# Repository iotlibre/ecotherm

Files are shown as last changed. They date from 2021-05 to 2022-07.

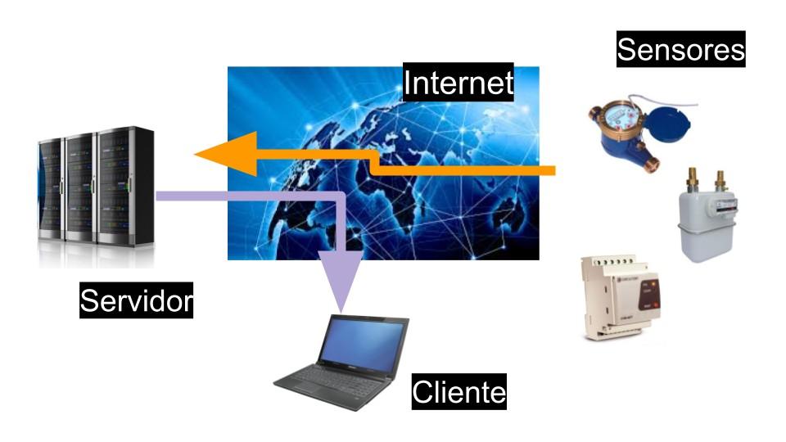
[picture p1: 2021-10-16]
images/iot_general.jpg

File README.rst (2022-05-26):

ecoTherm
==========
ecoTherm is designed to measure the thermal energy of an installation that has one or more water circuits at different temperatures. This device can measure:

* Temperature using 1-wire sensors
* Flow through pulses provided by water meters
* Analog values for both voltage and current.

.. image :: ./images/ecotherm_device.png

For temperature measurement and analog values, samples are taken in one-second intervals. The value provided, each time the information is transmitted, is the average of all the samples taken.

The pulses are measured by interruptions and the value provided, in each reporting period, is the number of interruptions accumulated since the last time the equipment was restarted.

ecoThermal can be installed on a DIN rail at a distance that allows communication with the sensors implemented in the installation. In a building we can have as many devices as are necessary and the server will integrate them in the same installation without the need for additional configurations or firmware changes. Communication is done through Wi-Fi so data cabling to the equipment is not necessary. Only ecoTherm needs to be within the coverage of the building's Wi-Fi network.

To use ecoTherm, computer knowledge is not necessary, although all developments and hardware are made under free licenses, which allows the modification and improvement of functionalities.

Main features
-------------
* 15 configurable inputs
* Supports up to 28 temperature probes spread over 7 buses
* It is possible to integrate up to 15 flow measurements
* Can measure up to 8 analog values
* Accuracy in temperature measurements: ± 0.5 ° C
* The precision of analog measurements depends on the probes used.
* The precision of the flow averages corresponds to the meters implemented
* Internet communication is done by local WIFI
* Configurable via Web
* Standard: IEEE 802.11 b / g / n
* 220 volt AC power supply. Range: 85 ~ 264VAC
* Din rail mounting
* The PCB integrates an Arduino nano with the ESP8266 12E
* Implements the MQTT protocol
* Compatible with `emonCMS <https://emoncms.org>`_

Hardware
--------
The hardware design is based on two PCBs that are interconnected by a ribbon cable. These two cards are machined in a din rail housing. This entire system is powered by 5 volt power supply. 

.. image :: ./images/ecotherm_board.png

Start up
--------
The ecoThermal set-up consists of three parts:

* Hardware configuration
* The Arduino firmware
* Configuration on installation

Hardware configuration
~~~~~~~~~~~~~~~~~~~~~~
The default hardware is prepared for 8 analog inputs, 3 flow rates and 16 temperature probes divided into 4 buses. However, this configuration can be modified by changing the surface components of the PCB until the combination of measures that best suits the project.

Arduino firmware
~~~~~~~~~~~~~~~~
The firmware that is loaded, by default, in the Arduino nano works correctly with the hardware configuration, by default. In the case of changing the hardware, it is also necessary to change the firmware of the Arduino integrated in the PCB and that can be found in the source code.

An ESP 8266 has been used for the internet connection. The firmware used for its operation has been developed by Open Energy Monintor and can be found at https://github.com/openenergymonitor/EmonESP. 

Configuration at installation
~~~~~~~~~~~~~~~~~~~~~~~~~~~~~
At this point, the parameters of the destination server and the local Wi-Fi to which the device will be connected are defined. To this end, the first time the ESP 8266 12E is put into service it will create its own access point, its own WIFI network. By connecting to any address, through this access point, the ESP configuration page will appear. Bear in mind that once ESP is configured and connected to a WIFI network, the router will assign you a single IP address that will be necessary to access to change the configuration.
The ESP configuration details can be found in the `repository <https: //github.com/openenergymonitor/EmonESP>`_

Source code
~~~~~~~~~~~
Copyright 2021 Endef Engineering SL.

Firmware code and hardware documentation can be found in this `repository <https://github.com/iotlibre/ecoTherm>`_ 

Both the hardware and the software of this repository have been developed by the company `Endef Engineering <https://endef.com/en/>`_ 

Licence
-------
* The hardware designs are licensed under a Creative Commons Attribution-ShareAlike 3.0 Unported License.
* The firmware is released under the GNU GPL V3 license The documentation is subject to GNU Free Documentation License
* The hardware designs follow the terms of the OSHW (Open-source hardware) Statement of Principles 1.0.

Disclaimer
----------

All the code found in this repository is under the license: "GNU V3 General Public License" so the conditions of its use are those included in this license

OUR PRODUCTS AND ASSEMBLY KITS MAY BE USED BY EXPERIENCED, SKILLED USERS, AT THEIR OWN RISK. TO THE FULLEST EXTENT PERMISSIBLE BY THE APPLICABLE LAW, WE HEREBY DISCLAIM ANY AND ALL RESPONSIBILITY, RISK, LIABILITY AND DAMAGES ARISING OUT OF DEATH OR PERSONAL INJURY RESULTING FROM ASSEMBLY OR OPERATION OF OUR PRODUCTS.

Your safety is your own responsibility, including proper use of equipment and safety gear, and determining whether you have adequate skill and experience. OEndef Engineering disclaims all responsibility for any resulting damage, injury, or expense. It is your responsibility to make sure that your activities comply with applicable laws, including copyright. There may be important updates or corrections. All use of the instructions, kits, projects and suggestions given by Endef Engineering are to be used at your own risk. The technology (hardware , firmware and software) are constantly changing, documentation (including build guide and instructions) may not be complete or correct.

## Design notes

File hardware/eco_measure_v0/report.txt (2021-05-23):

Información: Comprobando la huella del símbolo de la red "R15:/5FFCF40F:eco_power_v2:R_1206_HandSoldering".

Información: Comprobando la huella del símbolo de la red "C9:/5FF955E2:eco_power_v2:C_1206_HandSoldering".

Información: Comprobando la huella del símbolo de la red "R1:/5FFB1A2C:eco_power_v2:R_1206_HandSoldering".

Información: Comprobando la huella del símbolo de la red "C10:/5FFCF401:eco_power_v2:C_1206_HandSoldering".

Información: Comprobando la huella del símbolo de la red "R12:/5FFD79E8:eco_power_v2:R_1206_HandSoldering".

Información: Comprobando la huella del símbolo de la red "C11:/5FFD4082:eco_power_v2:C_1206_HandSoldering".

Información: Comprobando la huella del símbolo de la red "C12:/5FFD40B3:eco_power_v2:C_1206_HandSoldering".

Información: Comprobando la huella del símbolo de la red "R13:/5FFD7A19:eco_power_v2:R_1206_HandSoldering".

Información: Comprobando la huella del símbolo de la red "C13:/5FFD79D3:eco_power_v2:C_1206_HandSoldering".

Información: Comprobando la huella del símbolo de la red "U1:/5D4E51E2:eco_power_v2:arduino_nano".

Información: Comprobando la huella del símbolo de la red "R14:/5FF955F0:eco_power_v2:R_1206_HandSoldering".

Información: Comprobando la huella del símbolo de la red "C14:/5FFD7A04:eco_power_v2:C_1206_HandSoldering".

Información: Comprobando la huella del símbolo de la red "J5:/601390B1:TerminalBlock:TerminalBlock_bornier-6_P5.08mm".

Información: Comprobando la huella del símbolo de la red "R23:/5FFEF008:eco_power_v2:R_1206_HandSoldering".

Información: Comprobando la huella del símbolo de la red "C15:/5FFEEFC9:eco_power_v2:C_1206_HandSoldering".

Información: Comprobando la huella del símbolo de la red "P1:/5FF18B83:eco_power_v2:TerminalBlock_bornier-2_P5.08mm".

Información: Comprobando la huella del símbolo de la red "C16:/5FFEEFFA:eco_power_v2:C_1206_HandSoldering".

Información: Comprobando la huella del símbolo de la red "R22:/5FFEEFD7:eco_power_v2:R_1206_HandSoldering".

Información: Comprobando la huella del símbolo de la red "D1:/5D4E44AF:eco_power_v2:D_2114".

Información: Comprobando la huella del símbolo de la red "J1:/5D4CBA5C:eco_power_v2:Pin_Header_Straight_2x05_Pitch2.54mm_onsar".

Información: Comprobando la huella del símbolo de la red "R21:/5FFEF00F:eco_power_v2:R_1206_HandSoldering".

Información: Comprobando la huella del símbolo de la red "J4:/6011E7C7:TerminalBlock:TerminalBlock_bornier-6_P5.08mm".

Información: Comprobando la huella del símbolo de la red "R16:/5FFD4090:eco_power_v2:R_1206_HandSoldering".

Información: Comprobando la huella del símbolo de la red "R20:/5FFEEFDE:eco_power_v2:R_1206_HandSoldering".

Información: Comprobando la huella del símbolo de la red "J3:/60139D5D:TerminalBlock:TerminalBlock_bornier-3_P5.08mm".

Información: Comprobando la huella del símbolo de la red "R19:/5FFD7A12:eco_power_v2:R_1206_HandSoldering".

Información: Comprobando la huella del símbolo de la red "R17:/5FFD40C1:eco_power_v2:R_1206_HandSoldering".

Información: Comprobando la huella del símbolo de la red "J2:/60138EF1:TerminalBlock:TerminalBlock_bornier-6_P5.08mm".

Información: Comprobando la huella del símbolo de la red "R18:/5FFD79E1:eco_power_v2:R_1206_HandSoldering".

Información: Comprobando la huella del símbolo de la red "R2:/5FFFA8B2:eco_power_v2:R_1206_HandSoldering".

Información: Comprobando la huella del símbolo de la red "C3:/5FFFA89D:eco_power_v2:C_1206_HandSoldering".

Información: Comprobando la huella del símbolo de la red "C4:/5FFFF00A:eco_power_v2:C_1206_HandSoldering".

Información: Comprobando la huella del símbolo de la red "C5:/6004F39B:eco_power_v2:C_1206_HandSoldering".

Información: Comprobando la huella del símbolo de la red "R9:/5FFCF416:eco_power_v2:R_1206_HandSoldering".

Información: Comprobando la huella del símbolo de la red "R5:/6004F3D3:eco_power_v2:R_1206_HandSoldering".

Información: Comprobando la huella del símbolo de la red "C6:/6004F3BE:eco_power_v2:C_1206_HandSoldering".

Información: Comprobando la huella del símbolo de la red "R6:/6004F3F6:eco_power_v2:R_1206_HandSoldering".

Información: Comprobando la huella del símbolo de la red "R10:/5FFD4097:eco_power_v2:R_1206_HandSoldering".

Información: Comprobando la huella del símbolo de la red "C2:/5FFB1A03:eco_power_v2:C_1206_HandSoldering".

Información: Comprobando la huella del símbolo de la red "R4:/6004F3B0:eco_power_v2:R_1206_HandSoldering".

Información: Comprobando la huella del símbolo de la red "C7:/6004F3E1:eco_power_v2:C_1206_HandSoldering".

Información: Comprobando la huella del símbolo de la red "R11:/5FFD40C8:eco_power_v2:R_1206_HandSoldering".

Información: Comprobando la huella del símbolo de la red "R8:/5FF955F7:eco_power_v2:R_1206_HandSoldering".

Información: Comprobando la huella del símbolo de la red "C1:/5FF18B84:eco_power_v2:C_2220_HandSoldering".

Información: Comprobando la huella del símbolo de la red "W1:/5FF18B86:eco_power_v2:SolderWirePad_single_0-8mmDrill".

Información: Comprobando la huella del símbolo de la red "R7:/60054BE6:eco_power_v2:R_1206_HandSoldering".

Información: Comprobando la huella del símbolo de la red "R3:/5FFFF01F:eco_power_v2:R_1206_HandSoldering".

Información: Comprobando la huella del símbolo de la red "C8:/60054BD1:eco_power_v2:C_1206_HandSoldering".

Añadiendo del nuevo símbolo "R17:/5FFD40C1" la huella "eco_power_v2:R_1206_HandSoldering".

Cambiando de la huella "R3:/5FFFF01F" el nombre de la red del pad "2" de "" a "VCC".

Cambiando de la huella "R17:/5FFD40C1" el nombre de la red del pad "2" de "" a "/A3".

Añadiendo del nuevo símbolo "R15:/5FFCF40F" la huella "eco_power_v2:R_1206_HandSoldering".

Cambiando de la huella "R15:/5FFCF40F" el nombre de la red del pad "2" de "" a "/A1".

Cambiando de la huella "R8:/5FF955F7" el nombre de la red del pad "2" de "" a "/jA0".

Cambiando de la huella "R15:/5FFCF40F" el nombre de la red del pad "1" de "" a "GND".

Cambiando de la huella "R16:/5FFD4090" el nombre de la red del pad "2" de "" a "/A2".

Cambiando de la huella "R8:/5FF955F7" el nombre de la red del pad "1" de "" a "/A0".

Añadiendo del nuevo símbolo "R16:/5FFD4090" la huella "eco_power_v2:R_1206_HandSoldering".

Cambiando de la huella "R16:/5FFD4090" el nombre de la red del pad "1" de "" a "GND".

Añadiendo del nuevo símbolo "R8:/5FF955F7" la huella "eco_power_v2:R_1206_HandSoldering".

Añadiendo del nuevo símbolo "R10:/5FFD4097" la huella "eco_power_v2:R_1206_HandSoldering".

Añadiendo del nuevo símbolo "R11:/5FFD40C8" la huella "eco_power_v2:R_1206_HandSoldering".

Cambiando de la huella "R11:/5FFD40C8" el nombre de la red del pad "2" de "" a "/jA3".

Cambiando de la huella "R11:/5FFD40C8" el nombre de la red del pad "1" de "" a "/A3".

Cambiando de la huella "R10:/5FFD4097" el nombre de la red del pad "2" de "" a "/jA2".

Añadiendo del nuevo símbolo "R12:/5FFD79E8" la huella "eco_power_v2:R_1206_HandSoldering".

Cambiando de la huella "R10:/5FFD4097" el nombre de la red del pad "1" de "" a "/A2".

Cambiando de la huella "R7:/60054BE6" el nombre de la red del pad "2" de "" a "VCC".

Cambiando de la huella "R12:/5FFD79E8" el nombre de la red del pad "1" de "" a "/A4".

Cambiando de la huella "R12:/5FFD79E8" el nombre de la red del pad "2" de "" a "/jA4".

Cambiando de la huella "R14:/5FF955F0" el nombre de la red del pad "1" de "" a "GND".

Añadiendo del nuevo símbolo "R13:/5FFD7A19" la huella "eco_power_v2:R_1206_HandSoldering".

Cambiando de la huella "R13:/5FFD7A19" el nombre de la red del pad "2" de "" a "/jA5".

Cambiando de la huella "R13:/5FFD7A19" el nombre de la red del pad "1" de "" a "/A5".

Cambiando de la huella "R9:/5FFCF416" el nombre de la red del pad "2" de "" a "/jA1".

Cambiando de la huella "R9:/5FFCF416" el nombre de la red del pad "1" de "" a "/A1".

Añadiendo del nuevo símbolo "R14:/5FF955F0" la huella "eco_power_v2:R_1206_HandSoldering".

Añadiendo del nuevo símbolo "R9:/5FFCF416" la huella "eco_power_v2:R_1206_HandSoldering".

Cambiando de la huella "R14:/5FF955F0" el nombre de la red del pad "2" de "" a "/A0".

Cambiando de la huella "U1:/5D4E51E2" el nombre de la red del pad "1" de "" a "/ard_tx".

Cambiando de la huella "U1:/5D4E51E2" el nombre de la red del pad "16" de "" a "/D13".

Cambiando de la huella "U1:/5D4E51E2" el nombre de la red del pad "15" de "" a "/D12".

Cambiando de la huella "U1:/5D4E51E2" el nombre de la red del pad "14" de "" a "/D11".

Cambiando de la huella "U1:/5D4E51E2" el nombre de la red del pad "13" de "" a "/D10".

Cambiando de la huella "U1:/5D4E51E2" el nombre de la red del pad "12" de "" a "/D9".

Cambiando de la huella "U1:/5D4E51E2" el nombre de la red del pad "11" de "" a "/D8".

Cambiando de la huella "U1:/5D4E51E2" el nombre de la red del pad "10" de "" a "/D7".

Cambiando de la huella "U1:/5D4E51E2" el nombre de la red del pad "9" de "" a "/D6".

Cambiando de la huella "U1:/5D4E51E2" el nombre de la red del pad "8" de "" a "Net-(U1-Pad8)".

Cambiando de la huella "U1:/5D4E51E2" el nombre de la red del pad "7" de "" a "/D4".

Cambiando de la huella "U1:/5D4E51E2" el nombre de la red del pad "6" de "" a "/D3".

Cambiando de la huella "U1:/5D4E51E2" el nombre de la red del pad "5" de "" a "/D2".

Cambiando de la huella "U1:/5D4E51E2" el nombre de la red del pad "20" de "" a "/A1".

Cambiando de la huella "U1:/5D4E51E2" el nombre de la red del pad "17" de "" a "Net-(U1-Pad17)".

Cambiando de la huella "U1:/5D4E51E2" el nombre de la red del pad "18" de "" a "Net-(U1-Pad18)".

Cambiando de la huella "U1:/5D4E51E2" el nombre de la red del pad "19" de "" a "/A0".

Cambiando de la huella "U1:/5D4E51E2" el nombre de la red del pad "27" de "" a "VCC".

Cambiando de la huella "U1:/5D4E51E2" el nombre de la red del pad "28" de "" a "Net-(U1-Pad28)".

Cambiando de la huella "U1:/5D4E51E2" el nombre de la red del pad "29" de "" a "GND".

Cambiando de la huella "U1:/5D4E51E2" el nombre de la red del pad "30" de "" a "Net-(U1-Pad30)".

Cambiando de la huella "U1:/5D4E51E2" el nombre de la red del pad "4" de "" a "GND".

Cambiando de la huella "U1:/5D4E51E2" el nombre de la red del pad "3" de "" a "Net-(U1-Pad3)".

Cambiando de la huella "U1:/5D4E51E2" el nombre de la red del pad "2" de "" a "/ard_rx".

Añadiendo del nuevo símbolo "W1:/5FF18B86" la huella "eco_power_v2:SolderWirePad_single_0-8mmDrill".

Cambiando de la huella "W1:/5FF18B86" el nombre de la red del pad "1" de "" a "VCC".

Añadiendo del nuevo símbolo "R22:/5FFEEFD7" la huella "eco_power_v2:R_1206_HandSoldering".

Añadiendo del nuevo símbolo "R18:/5FFD79E1" la huella "eco_power_v2:R_1206_HandSoldering".

Cambiando de la huella "R18:/5FFD79E1" el nombre de la red del pad "2" de "" a "/A4".

Cambiando de la huella "R18:/5FFD79E1" el nombre de la red del pad "1" de "" a "GND".

Añadiendo del nuevo símbolo "R19:/5FFD7A12" la huella "eco_power_v2:R_1206_HandSoldering".

Cambiando de la huella "R19:/5FFD7A12" el nombre de la red del pad "1" de "" a "GND".

Cambiando de la huella "R19:/5FFD7A12" el nombre de la red del pad "2" de "" a "/A5".

Añadiendo del nuevo símbolo "R20:/5FFEEFDE" la huella "eco_power_v2:R_1206_HandSoldering".

Cambiando de la huella "R20:/5FFEEFDE" el nombre de la red del pad "2" de "" a "/jA6".

Cambiando de la huella "R20:/5FFEEFDE" el nombre de la red del pad "1" de "" a "/A6".

Añadiendo del nuevo símbolo "R21:/5FFEF00F" la huella "eco_power_v2:R_1206_HandSoldering".

Cambiando de la huella "R21:/5FFEF00F" el nombre de la red del pad "2" de "" a "/jA7".

Cambiando de la huella "R21:/5FFEF00F" el nombre de la red del pad "1" de "" a "/A7".

Cambiando de la huella "R17:/5FFD40C1" el nombre de la red del pad "1" de "" a "GND".

Cambiando de la huella "R22:/5FFEEFD7" el nombre de la red del pad "1" de "" a "GND".

Cambiando de la huella "R22:/5FFEEFD7" el nombre de la red del pad "2" de "" a "/A6".

Añadiendo del nuevo símbolo "R23:/5FFEF008" la huella "eco_power_v2:R_1206_HandSoldering".

Cambiando de la huella "R23:/5FFEF008" el nombre de la red del pad "1" de "" a "GND".

Cambiando de la huella "R23:/5FFEF008" el nombre de la red del pad "2" de "" a "/A7".

Añadiendo del nuevo símbolo "U1:/5D4E51E2" la huella "eco_power_v2:arduino_nano".

Cambiando de la huella "U1:/5D4E51E2" el nombre de la red del pad "26" de "" a "/A7".

Cambiando de la huella "U1:/5D4E51E2" el nombre de la red del pad "25" de "" a "/A6".

Cambiando de la huella "U1:/5D4E51E2" el nombre de la red del pad "24" de "" a "/A5".

Cambiando de la huella "U1:/5D4E51E2" el nombre de la red del pad "23" de "" a "/A4".

Cambiando de la huella "U1:/5D4E51E2" el nombre de la red del pad "22" de "" a "/A3".

Cambiando de la huella "U1:/5D4E51E2" el nombre de la red del pad "21" de "" a "/A2".

Añadiendo del nuevo símbolo "C15:/5FFEEFC9" la huella "eco_power_v2:C_1206_HandSoldering".

Añadiendo del nuevo símbolo "C11:/5FFD4082" la huella "eco_power_v2:C_1206_HandSoldering".

Cambiando de la huella "C11:/5FFD4082" el nombre de la red del pad "2" de "" a "GND".

Cambiando de la huella "C11:/5FFD4082" el nombre de la red del pad "1" de "" a "/A2".

Añadiendo del nuevo símbolo "C12:/5FFD40B3" la huella "eco_power_v2:C_1206_HandSoldering".

Cambiando de la huella "C12:/5FFD40B3" el nombre de la red del pad "1" de "" a "/A3".

Cambiando de la huella "C12:/5FFD40B3" el nombre de la red del pad "2" de "" a "GND".

Añadiendo del nuevo símbolo "C13:/5FFD79D3" la huella "eco_power_v2:C_1206_HandSoldering".

Cambiando de la huella "C13:/5FFD79D3" el nombre de la red del pad "2" de "" a "GND".

Cambiando de la huella "C13:/5FFD79D3" el nombre de la red del pad "1" de "" a "/A4".

Añadiendo del nuevo símbolo "C14:/5FFD7A04" la huella "eco_power_v2:C_1206_HandSoldering".

Cambiando de la huella "C14:/5FFD7A04" el nombre de la red del pad "1" de "" a "/A5".

Cambiando de la huella "C14:/5FFD7A04" el nombre de la red del pad "2" de "" a "GND".

Cambiando de la huella "C10:/5FFCF401" el nombre de la red del pad "2" de "" a "GND".

Cambiando de la huella "C15:/5FFEEFC9" el nombre de la red del pad "1" de "" a "/A6".

Cambiando de la huella "C15:/5FFEEFC9" el nombre de la red del pad "2" de "" a "GND".

Añadiendo del nuevo símbolo "C16:/5FFEEFFA" la huella "eco_power_v2:C_1206_HandSoldering".

Cambiando de la huella "C16:/5FFEEFFA" el nombre de la red del pad "2" de "" a "GND".

Cambiando de la huella "C16:/5FFEEFFA" el nombre de la red del pad "1" de "" a "/A7".

Añadiendo del nuevo símbolo "J1:/5D4CBA5C" la huella "eco_power_v2:Pin_Header_Straight_2x05_Pitch2.54mm_onsar".

Cambiando de la huella "J1:/5D4CBA5C" el nombre de la red del pad "10" de "" a "GND".

Cambiando de la huella "J1:/5D4CBA5C" el nombre de la red del pad "9" de "" a "/vcc_5v".

Cambiando de la huella "J1:/5D4CBA5C" el nombre de la red del pad "8" de "" a "/D9".

Cambiando de la huella "J1:/5D4CBA5C" el nombre de la red del pad "7" de "" a "/vcc_5v".

Cambiando de la huella "J1:/5D4CBA5C" el nombre de la red del pad "6" de "" a "/D8".

Cambiando de la huella "C6:/6004F3BE" el nombre de la red del pad "2" de "" a "GND".

Añadiendo del nuevo símbolo "C1:/5FF18B84" la huella "eco_power_v2:C_2220_HandSoldering".

Cambiando de la huella "C1:/5FF18B84" el nombre de la red del pad "2" de "" a "GND".

Cambiando de la huella "C1:/5FF18B84" el nombre de la red del pad "1" de "" a "VCC".

Añadiendo del nuevo símbolo "C2:/5FFB1A03" la huella "eco_power_v2:C_1206_HandSoldering".

Cambiando de la huella "C2:/5FFB1A03" el nombre de la red del pad "2" de "" a "GND".

Cambiando de la huella "C2:/5FFB1A03" el nombre de la red del pad "1" de "" a "/D2".

Añadiendo del nuevo símbolo "C5:/6004F39B" la huella "eco_power_v2:C_1206_HandSoldering".

Cambiando de la huella "C5:/6004F39B" el nombre de la red del pad "2" de "" a "GND".

Cambiando de la huella "C5:/6004F39B" el nombre de la red del pad "1" de "" a "/D10".

Añadiendo del nuevo símbolo "C6:/6004F3BE" la huella "eco_power_v2:C_1206_HandSoldering".

Cambiando de la huella "C6:/6004F3BE" el nombre de la red del pad "1" de "" a "/D11".

Añadiendo del nuevo símbolo "R7:/60054BE6" la huella "eco_power_v2:R_1206_HandSoldering".

Añadiendo del nuevo símbolo "C7:/6004F3E1" la huella "eco_power_v2:C_1206_HandSoldering".

Cambiando de la huella "C7:/6004F3E1" el nombre de la red del pad "2" de "" a "GND".

Cambiando de la huella "C7:/6004F3E1" el nombre de la red del pad "1" de "" a "/D12".

Añadiendo del nuevo símbolo "C8:/60054BD1" la huella "eco_power_v2:C_1206_HandSoldering".

Cambiando de la huella "C8:/60054BD1" el nombre de la red del pad "1" de "" a "/D13".

Cambiando de la huella "C8:/60054BD1" el nombre de la red del pad "2" de "" a "GND".

Añadiendo del nuevo símbolo "C9:/5FF955E2" la huella "eco_power_v2:C_1206_HandSoldering".

Cambiando de la huella "C9:/5FF955E2" el nombre de la red del pad "2" de "" a "GND".

Cambiando de la huella "C9:/5FF955E2" el nombre de la red del pad "1" de "" a "/A0".

Añadiendo del nuevo símbolo "C10:/5FFCF401" la huella "eco_power_v2:C_1206_HandSoldering".

Cambiando de la huella "C10:/5FFCF401" el nombre de la red del pad "1" de "" a "/A1".

Añadiendo del nuevo símbolo "R3:/5FFFF01F" la huella "eco_power_v2:R_1206_HandSoldering".

Cambiando de la huella "J5:/601390B1" el nombre de la red del pad "3" de "" a "/jA1".

Cambiando de la huella "J5:/601390B1" el nombre de la red del pad "1" de "" a "/vcc_5v".

Cambiando de la huella "J5:/601390B1" el nombre de la red del pad "4" de "" a "/jA2".

Cambiando de la huella "J5:/601390B1" el nombre de la red del pad "5" de "" a "/jA3".

Cambiando de la huella "J5:/601390B1" el nombre de la red del pad "6" de "" a "GND".

Añadiendo del nuevo símbolo "P1:/5FF18B83" la huella "eco_power_v2:TerminalBlock_bornier-2_P5.08mm".

Cambiando de la huella "P1:/5FF18B83" el nombre de la red del pad "2" de "" a "/vcc_5v".

Cambiando de la huella "P1:/5FF18B83" el nombre de la red del pad "1" de "" a "GND".

Añadiendo del nuevo símbolo "R1:/5FFB1A2C" la huella "eco_power_v2:R_1206_HandSoldering".

Cambiando de la huella "R1:/5FFB1A2C" el nombre de la red del pad "1" de "" a "/D2".

Cambiando de la huella "R1:/5FFB1A2C" el nombre de la red del pad "2" de "" a "VCC".

Cambiando de la huella "J1:/5D4CBA5C" el nombre de la red del pad "4" de "" a "/D7".

Cambiando de la huella "R3:/5FFFF01F" el nombre de la red del pad "1" de "" a "/D4".

Añadiendo del nuevo símbolo "R4:/6004F3B0" la huella "eco_power_v2:R_1206_HandSoldering".

Cambiando de la huella "R4:/6004F3B0" el nombre de la red del pad "2" de "" a "VCC".

Cambiando de la huella "R4:/6004F3B0" el nombre de la red del pad "1" de "" a "/D10".

Añadiendo del nuevo símbolo "R5:/6004F3D3" la huella "eco_power_v2:R_1206_HandSoldering".

Cambiando de la huella "R5:/6004F3D3" el nombre de la red del pad "1" de "" a "/D11".

Cambiando de la huella "R5:/6004F3D3" el nombre de la red del pad "2" de "" a "VCC".

Añadiendo del nuevo símbolo "R6:/6004F3F6" la huella "eco_power_v2:R_1206_HandSoldering".

Cambiando de la huella "R6:/6004F3F6" el nombre de la red del pad "2" de "" a "VCC".

Cambiando de la huella "R6:/6004F3F6" el nombre de la red del pad "1" de "" a "/D12".

Cambiando de la huella "R7:/60054BE6" el nombre de la red del pad "1" de "" a "/D13".

Añadiendo del nuevo símbolo "J5:/601390B1" la huella "TerminalBlock:TerminalBlock_bornier-6_P5.08mm".

Cambiando de la huella "J1:/5D4CBA5C" el nombre de la red del pad "5" de "" a "GND".

Cambiando de la huella "J1:/5D4CBA5C" el nombre de la red del pad "3" de "" a "/ard_rx".

Cambiando de la huella "J1:/5D4CBA5C" el nombre de la red del pad "2" de "" a "/D6".

Cambiando de la huella "J1:/5D4CBA5C" el nombre de la red del pad "1" de "" a "/ard_tx".

Añadiendo del nuevo símbolo "J2:/60138EF1" la huella "TerminalBlock:TerminalBlock_bornier-6_P5.08mm".

Cambiando de la huella "J2:/60138EF1" el nombre de la red del pad "6" de "" a "GND".

Cambiando de la huella "J2:/60138EF1" el nombre de la red del pad "5" de "" a "/jA7".

Cambiando de la huella "J2:/60138EF1" el nombre de la red del pad "4" de "" a "/jA6".

Cambiando de la huella "J2:/60138EF1" el nombre de la red del pad "1" de "" a "/vcc_5v".

Cambiando de la huella "J2:/60138EF1" el nombre de la red del pad "3" de "" a "/jA5".

Cambiando de la huella "J5:/601390B1" el nombre de la red del pad "2" de "" a "/jA0".

Cambiando de la huella "J2:/60138EF1" el nombre de la red del pad "2" de "" a "/jA4".

Añadiendo del nuevo símbolo "J3:/60139D5D" la huella "TerminalBlock:TerminalBlock_bornier-3_P5.08mm".

Cambiando de la huella "J3:/60139D5D" el nombre de la red del pad "1" de "" a "/D3".

Cambiando de la huella "J3:/60139D5D" el nombre de la red del pad "2" de "" a "/D2".

Cambiando de la huella "J3:/60139D5D" el nombre de la red del pad "3" de "" a "GND".

Añadiendo del nuevo símbolo "J4:/6011E7C7" la huella "TerminalBlock:TerminalBlock_bornier-6_P5.08mm".

Cambiando de la huella "J4:/6011E7C7" el nombre de la red del pad "2" de "" a "/D13".

Cambiando de la huella "J4:/6011E7C7" el nombre de la red del pad "3" de "" a "/D12".

Cambiando de la huella "J4:/6011E7C7" el nombre de la red del pad "1" de "" a "/vcc_5v".

Cambiando de la huella "J4:/6011E7C7" el nombre de la red del pad "4" de "" a "/D11".

Cambiando de la huella "J4:/6011E7C7" el nombre de la red del pad "5" de "" a "/D10".

Cambiando de la huella "J4:/6011E7C7" el nombre de la red del pad "6" de "" a "/D4".

Aviso: Ha cambiado la huella del símbolo "D1": huella en placa "Diodes_SMD:D_2114", huella en listado de redes "eco_power_v2:D_2114"

Aviso: Ha cambiado la huella del símbolo "C4": huella en placa "Capacitors_SMD:C_2220_HandSoldering", huella en listado de redes "eco_power_v2:C_1206_HandSoldering"

Aviso: Ha cambiado la huella del símbolo "C3": huella en placa "Capacitors_SMD:C_1206_HandSoldering", huella en listado de redes "eco_power_v2:C_1206_HandSoldering"

Aviso: Ha cambiado la huella del símbolo "R2": huella en placa "Resistors_SMD:R_1206_HandSoldering", huella en listado de redes "eco_power_v2:R_1206_HandSoldering"

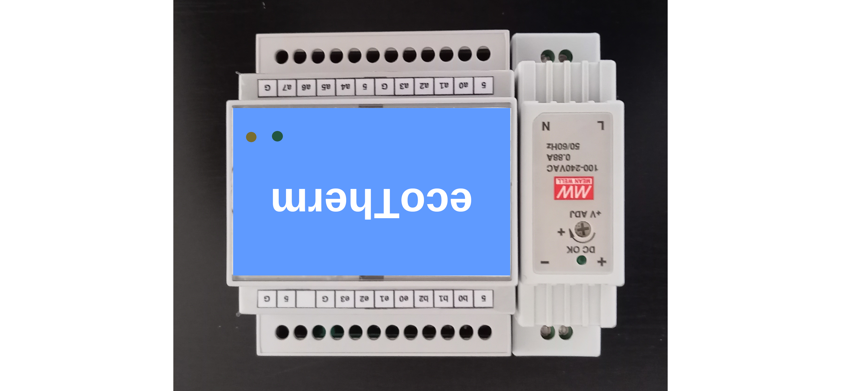
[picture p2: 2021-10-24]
images/ecotherm_device.png

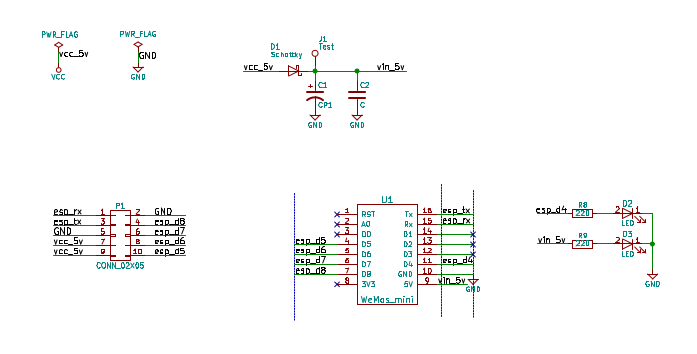
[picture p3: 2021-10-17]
images/iotesp.png

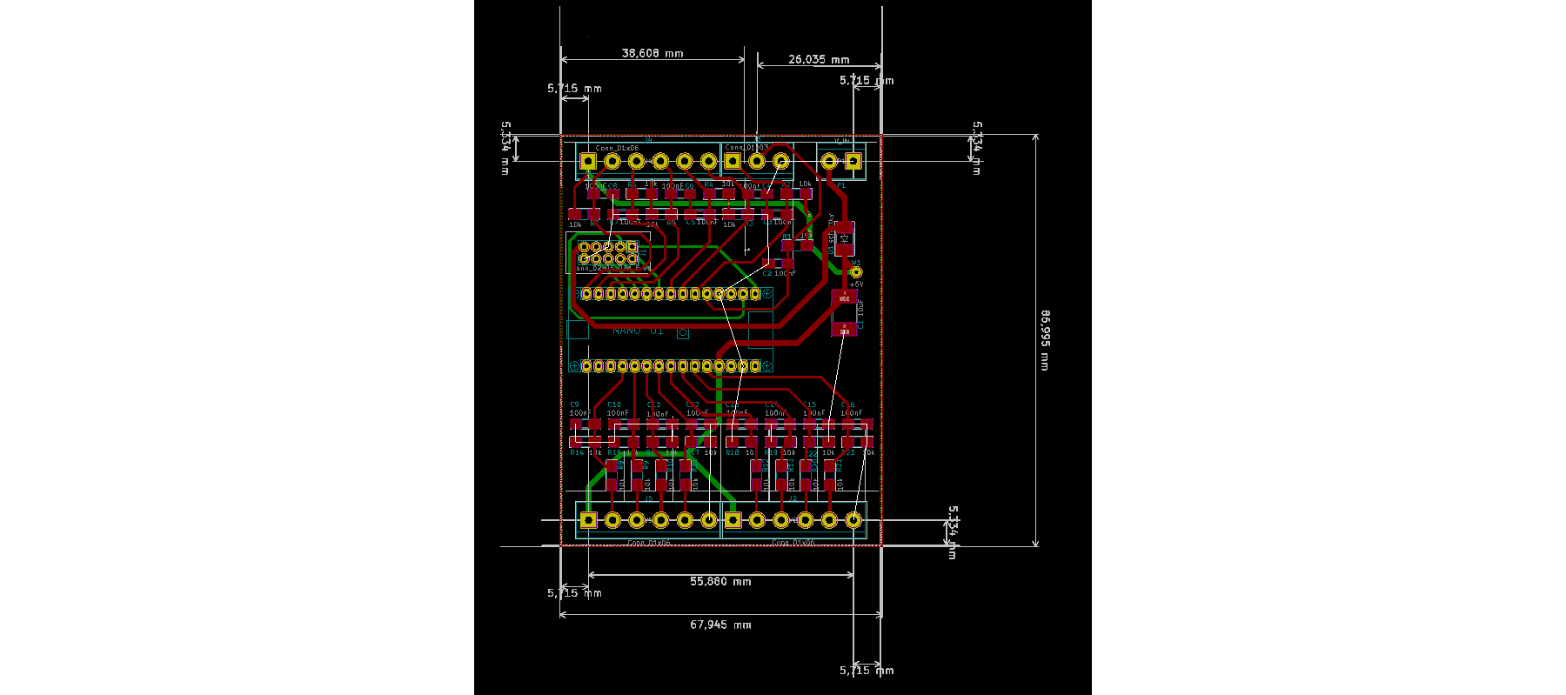
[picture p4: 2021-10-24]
images/ecotherm_board.png

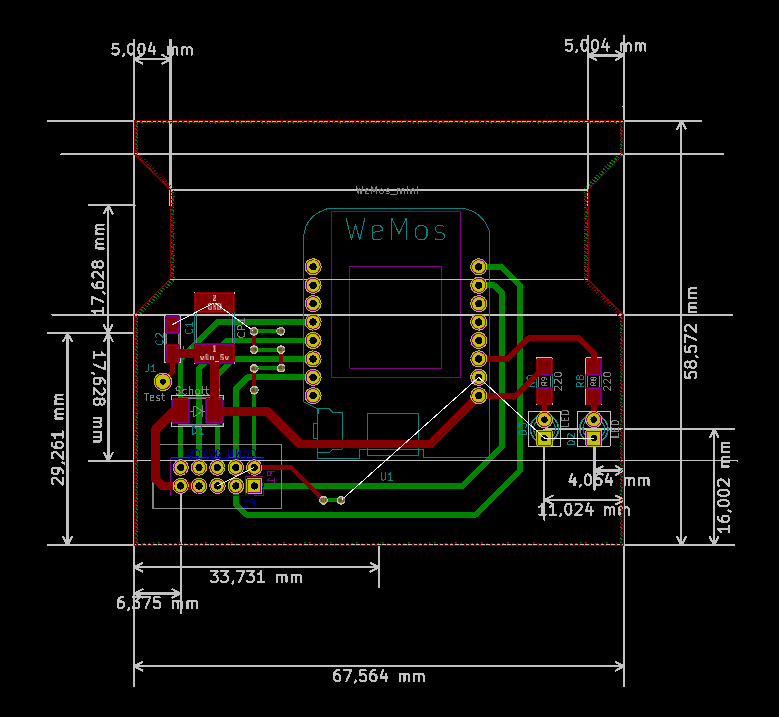
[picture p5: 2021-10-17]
images/esp_board.png

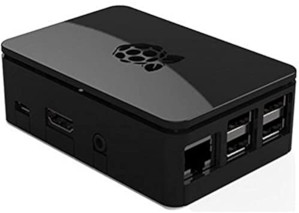
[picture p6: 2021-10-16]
images/raspberrypi.jpg

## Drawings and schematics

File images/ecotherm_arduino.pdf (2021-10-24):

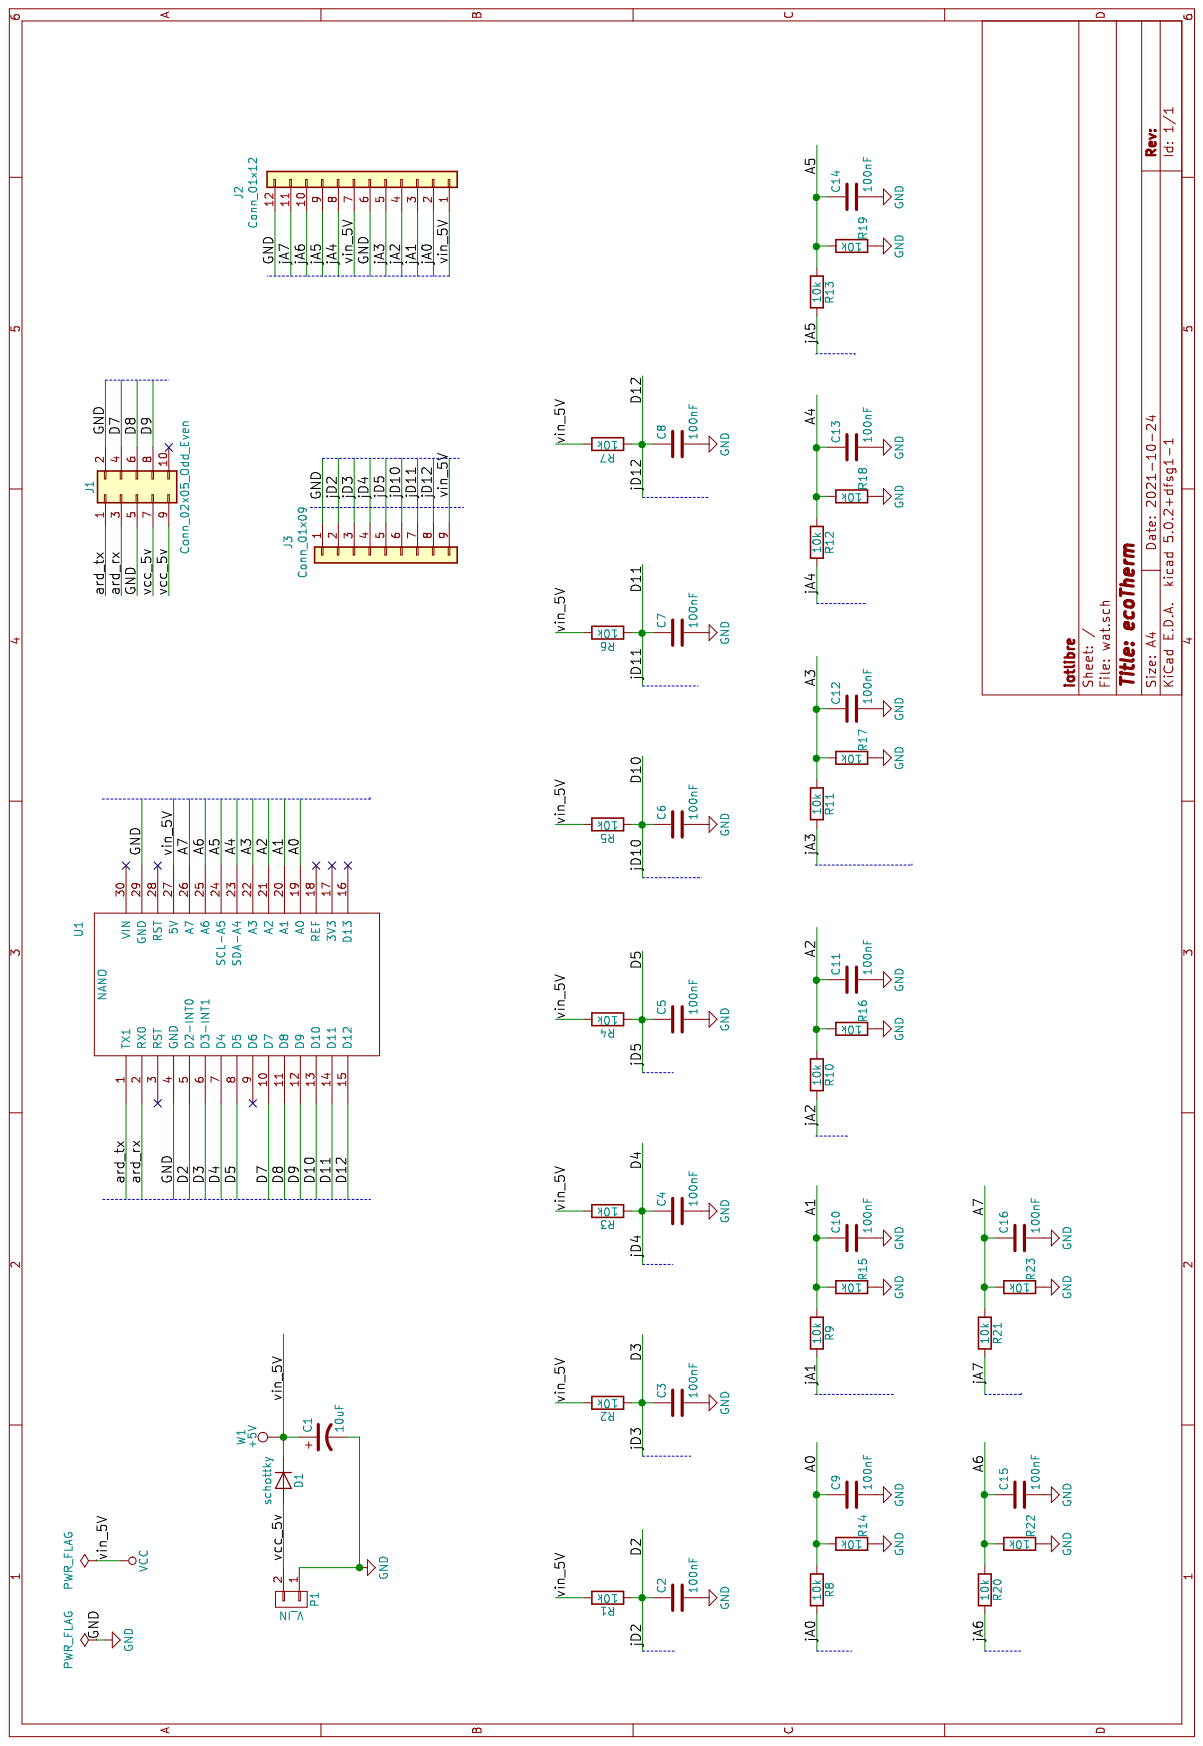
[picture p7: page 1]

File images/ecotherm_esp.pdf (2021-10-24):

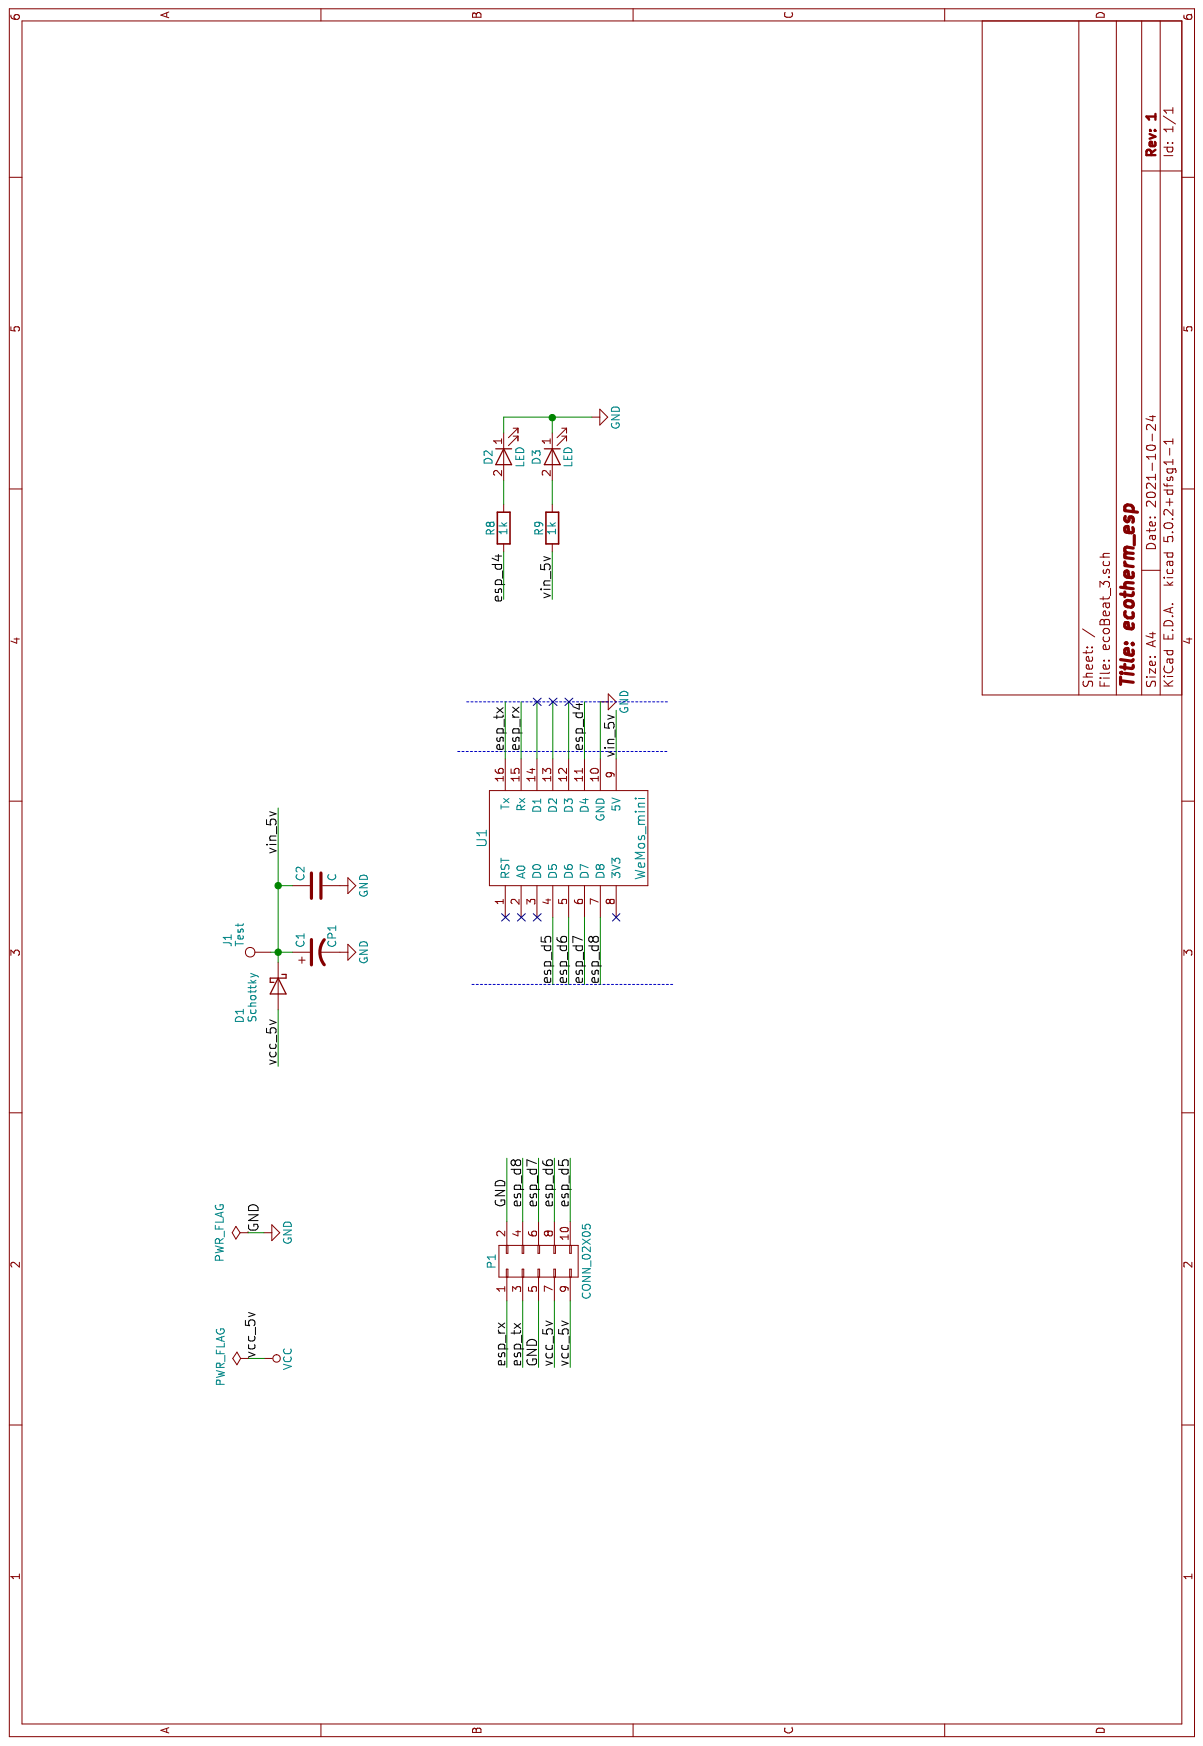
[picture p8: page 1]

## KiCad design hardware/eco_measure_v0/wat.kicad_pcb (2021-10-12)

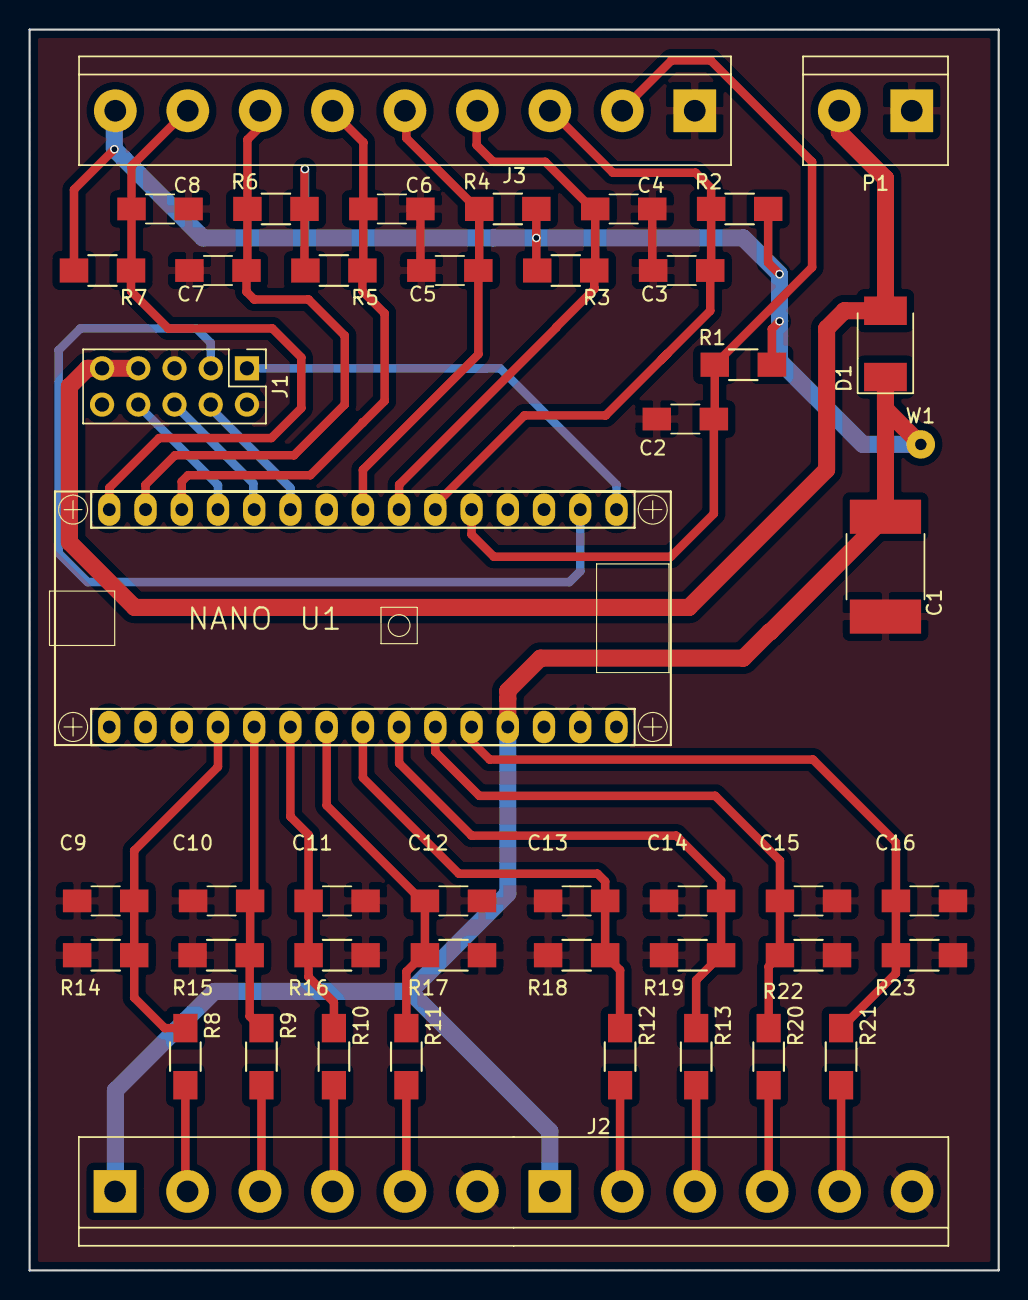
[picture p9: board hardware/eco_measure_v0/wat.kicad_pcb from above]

Board: 2 copper layers, 67.9 x 87.0 mm, 46 parts (0 on the bottom side), 31 nets.

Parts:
C1: 10uF; C_2220_HandSoldering
C2, C3, C4, C5, C6, C7, C8, C9, C10, C11, C12, C13, C14, C15, C16: 100nF; C_1206_HandSoldering
D1: schottky; D_2114
J1: Conn_02x05_Odd_Even; Pin_Header_Straight_2x05_Pitch2.54mm_onsar
J2: Conn_01x12; TerminalBlock_bornier-12_P5.08mm
J3: Conn_01x09; TerminalBlock_bornier-9_P5.08mm
P1: V_IN; TerminalBlock_bornier-2_P5.08mm
R1, R2, R3, R4, R5, R6, R7, R8, R9, R10, R11, R12, R13, R14, R15, R16, R17, R18, R19, R20, R21, R22, R23: 10k; R_1206_HandSoldering
U1: NANO; arduino_nano
W1: +5V; SolderWirePad_single_0-8mmDrill

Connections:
/A0: C9.1, R8.1, R14.2, U1.19
/A1: C10.1, R9.1, R15.2, U1.20
/A2: C11.1, R10.1, R16.2, U1.21
/A3: C12.1, R11.1, R17.2, U1.22
/A4: C13.1, R12.1, R18.2, U1.23
/A5: C14.1, R13.1, R19.2, U1.24
/A6: C15.1, R20.1, R22.2, U1.25
/A7: C16.1, R21.1, R23.2, U1.26
/D2: C2.1, J3.2, R1.1, U1.5
/D3: C3.1, J3.3, R2.1, U1.6
/D4: C4.1, J3.4, R3.1, U1.7
/D5: C5.1, J3.5, R4.1, U1.8
/D7: J1.4, U1.10
/D8: J1.6, U1.11
/D9: J1.8, U1.12
/D10: C6.1, J3.6, R5.1, U1.13
/D11: C7.1, J3.7, R6.1, U1.14
/D12: C8.1, J3.8, R7.1, U1.15
/ard_rx: J1.3, U1.2
/ard_tx: J1.1, U1.1
/jA0: J2.2, R8.2
/jA1: J2.3, R9.2
/jA2: J2.4, R10.2
/jA3: J2.5, R11.2
/jA4: J2.8, R12.2
/jA5: J2.9, R13.2
/jA6: J2.10, R20.2
/jA7: J2.11, R21.2
/vcc_5v: D1.2, J1.7, J1.9, P1.2
GND: C1.2, C2.2, C3.2, C4.2, C5.2, C6.2, C7.2, C8.2, C9.2, C10.2, C11.2, C12.2, C13.2, C14.2, C15.2, C16.2, J1.2, J1.5, J2.6, J2.12, J3.1, P1.1, R14.1, R15.1, R16.1, R17.1, R18.1, R19.1, R22.1, R23.1, U1.4, U1.29
VCC: C1.1, D1.1, J2.1, J2.7, J3.9, R1.2, R2.2, R3.2, R4.2, R5.2, R6.2, R7.2, U1.27, W1.1

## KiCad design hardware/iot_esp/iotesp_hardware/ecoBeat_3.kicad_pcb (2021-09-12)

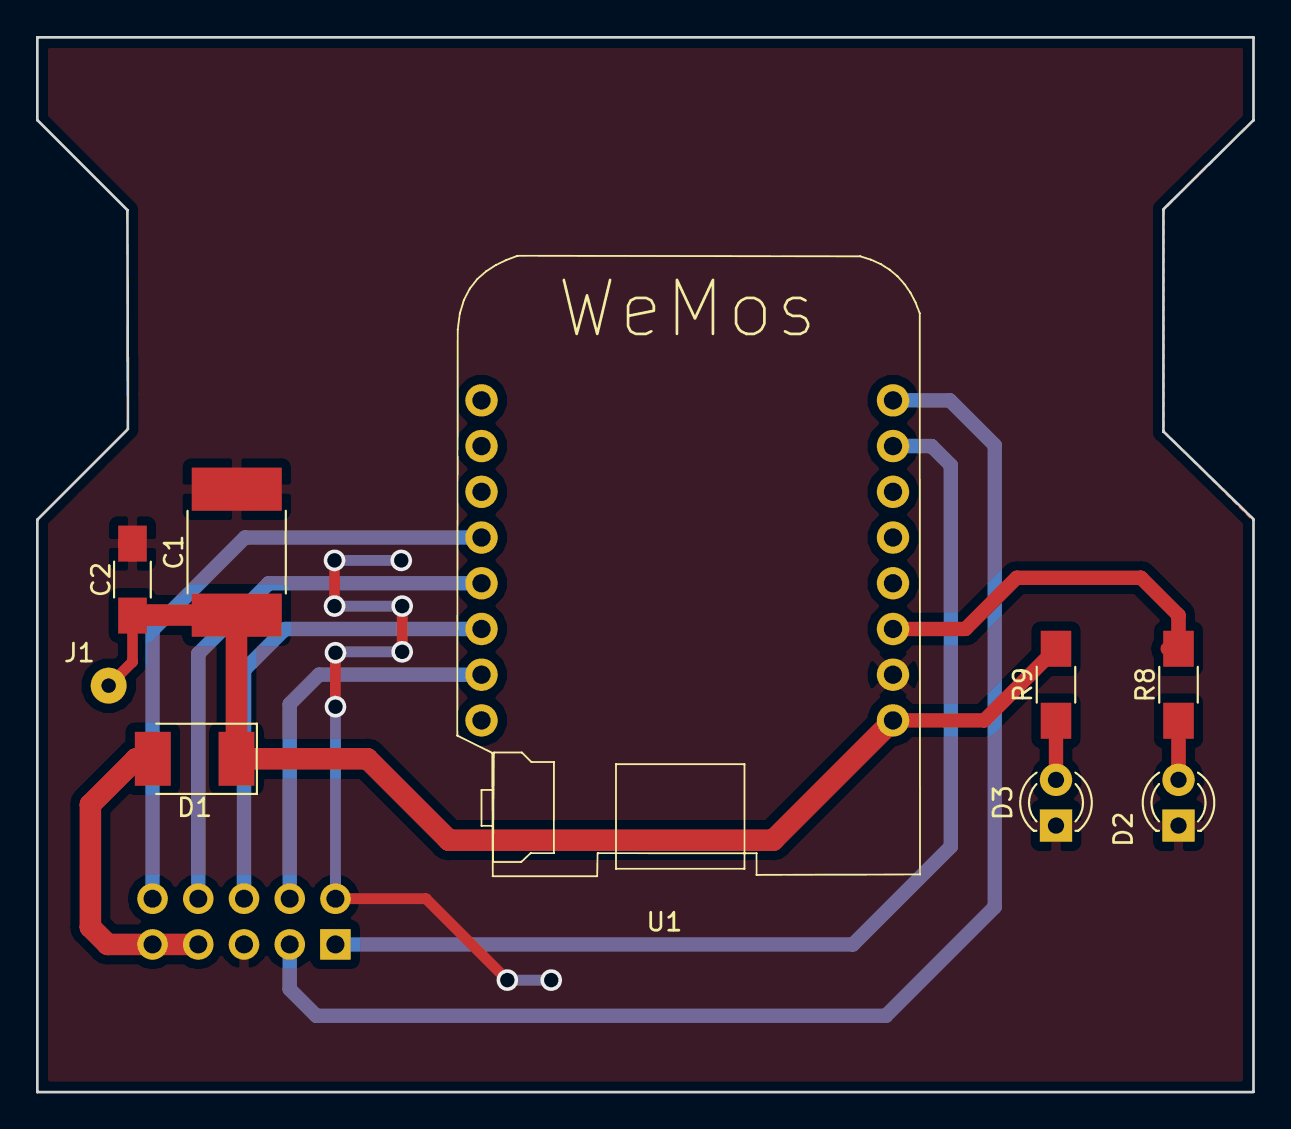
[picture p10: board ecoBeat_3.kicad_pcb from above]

Board: 2 copper layers, 67.6 x 58.6 mm, 10 parts (1 on the bottom side), 12 nets.

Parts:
C1: CP1; C_2220_HandSoldering
C2: C; C_1206_HandSoldering
D1: Schottky; D_2114
D2, D3: LED; LED_D3.0mm
J1: Test; SolderWirePad_single_0-8mmDrill
P1: CONN_02X05; Pin_Header_Straight_2x05_Pitch2.54mm_onsar
R8, R9: 220; R_1206_HandSoldering
U1: WeMos_mini; D1_mini_board_oscar

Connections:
/esp_d4: R8.2, U1.11
/esp_d5: P1.10, U1.4
/esp_d6: P1.8, U1.5
/esp_d7: P1.6, U1.6
/esp_d8: P1.4, U1.7
/esp_rx: P1.1, U1.15
/esp_tx: P1.3, U1.16
/vin_5v: C1.1, C2.1, D1.1, J1.1, R9.2, U1.9
GND: C1.2, C2.2, D2.1, D3.1, P1.2, P1.5, U1.10
unnamed: D2.2, R8.1
unnamed: D3.2, R9.1
VCC: D1.2, P1.7, P1.9

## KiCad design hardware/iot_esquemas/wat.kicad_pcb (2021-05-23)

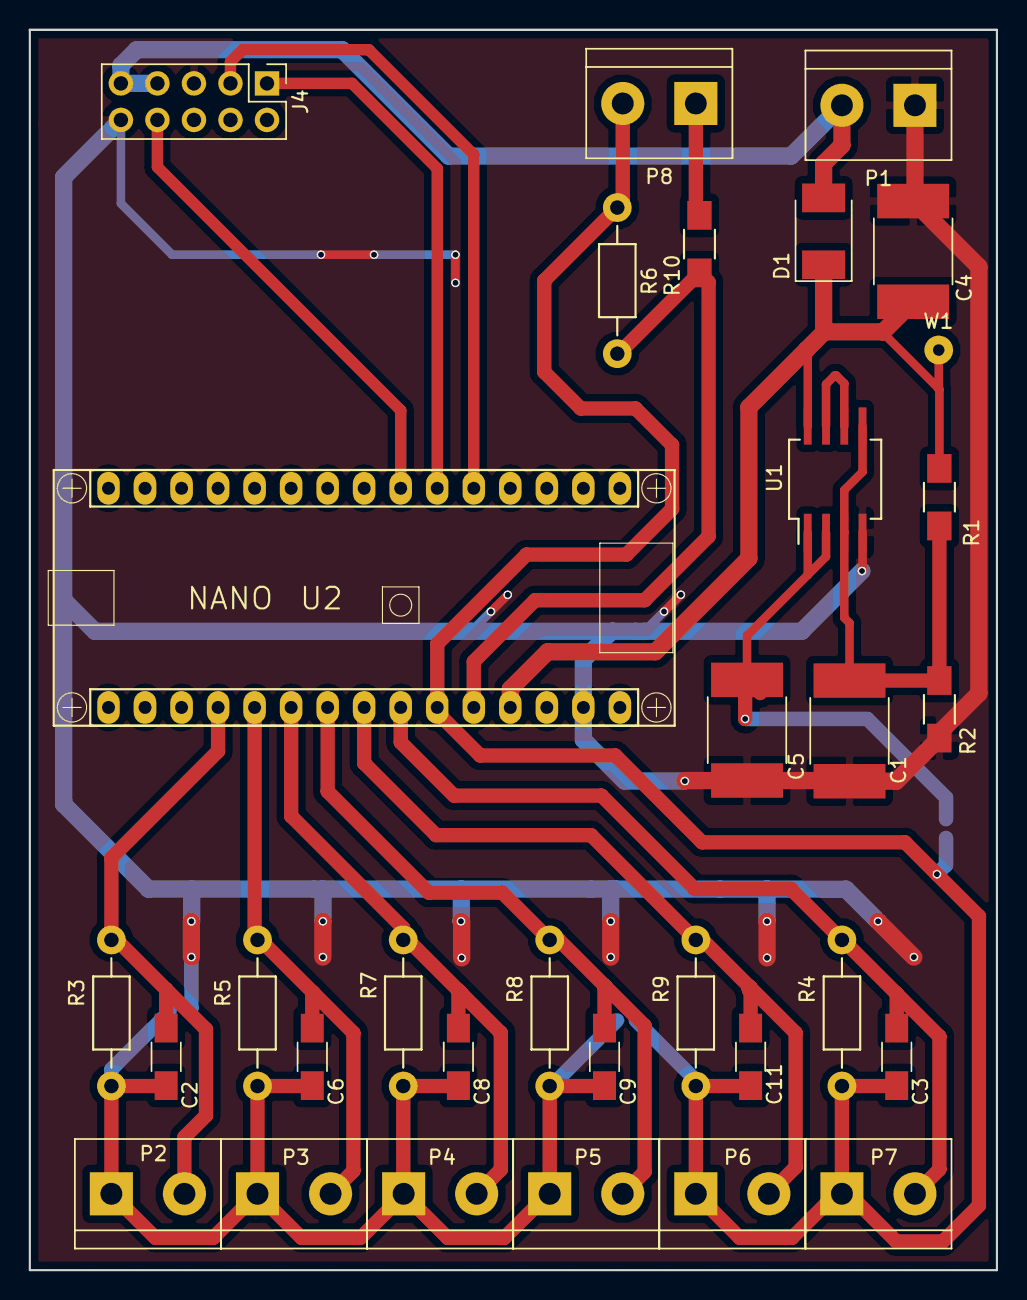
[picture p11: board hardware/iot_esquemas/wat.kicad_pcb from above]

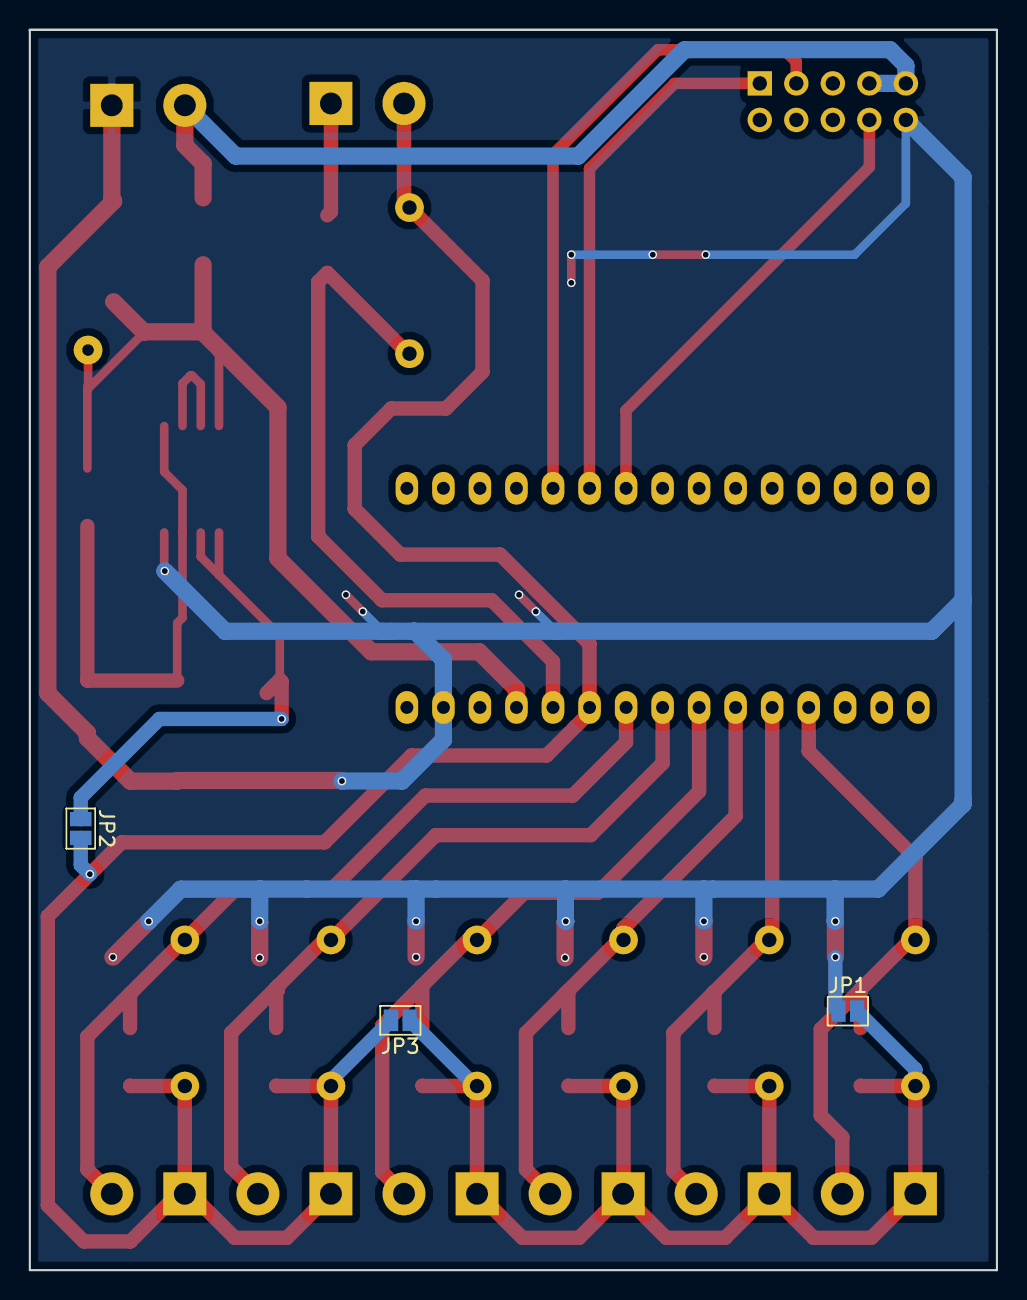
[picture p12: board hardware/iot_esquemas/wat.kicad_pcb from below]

Board: 2 copper layers, 67.2 x 86.2 mm, 35 parts (3 on the bottom side), 19 nets.

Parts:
C1, C4, C5: 10uF; C_2220_HandSoldering
C2, C3, C6, C8, C9, C11: 100nF; C_1206_HandSoldering
D1: schottky; D_2114
J4: Conn_02x05_Odd_Even; Pin_Header_Straight_2x05_Pitch2.54mm_onsar
JP1, JP2, JP3: Jumper_2_Open; SolderJumper-2_P1.3mm_Open_Pad1.0x1.5mm
P1: V_IN; TerminalBlock_bornier-2_P5.08mm
P2: PINZA_1; TerminalBlock_bornier-2_P5.08mm
P3: PINZA_2; TerminalBlock_bornier-2_P5.08mm
P4: PINZA_3; TerminalBlock_bornier-2_P5.08mm
P5: PINZA_4; TerminalBlock_bornier-2_P5.08mm
P6: PINZA_5; TerminalBlock_bornier-2_P5.08mm
P7: PINZA_6; TerminalBlock_bornier-2_P5.08mm
P8: PINZA_7; TerminalBlock_bornier-2_P5.08mm
R1, R2: 4K7; R_1206_HandSoldering
R3, R4, R5, R7, R8, R9: 10k; Resistor_Horizontal_RM10mm
R6: 1k; Resistor_Horizontal_RM10mm
R10: 10k; R_1206_HandSoldering
U1: LM358; SO-8_5.3x6.2mm_Pitch1.27mm
U2: NANO; arduino_nano
W1: +5V; SolderWirePad_single_0-8mmDrill

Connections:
/ard_d4: J4.8, U2.7
/ard_rx: J4.3, U2.5
/ard_tx: J4.1, U2.6
/intensidad_1: C2.1, P2.2, R3.1, U2.19
/intensidad_2: C6.1, P3.2, R5.1, U2.20
/intensidad_3: C8.1, P4.2, R7.1, U2.21
/intensidad_4: C9.1, P5.2, R8.1, U2.22
/intensidad_5: C11.1, P6.2, R9.1, U2.23
/intensidad_6: C3.1, P7.2, R4.1, U2.24
/v_25: C1.1, R1.2, R2.1, U1.3, U1.5
/v_comun_0: C2.2, C6.2, C8.2, C9.2, JP1.2, JP3.1, P2.1, P3.1, P4.1, P5.1, R3.2, R5.2, R7.2, R8.2
/v_comun_1: C3.2, C11.2, JP2.2, JP3.2, P6.1, P7.1, P8.2, R4.2, R6.2, R9.2, U2.25
/v_op: C5.1, JP2.1, U1.1, U1.2
/vcc_5v: D1.2, J4.7, J4.9, P1.2
/voltage_1: R6.1, R10.1, U2.26
GND: C1.2, C4.2, C5.2, J4.5, J4.10, JP1.1, P1.1, R2.2, U1.4, U2.29
unnamed: P8.1, R10.2
unnamed: U1.6, U1.7
VCC: C4.1, D1.1, R1.1, U1.8, U2.27, W1.1

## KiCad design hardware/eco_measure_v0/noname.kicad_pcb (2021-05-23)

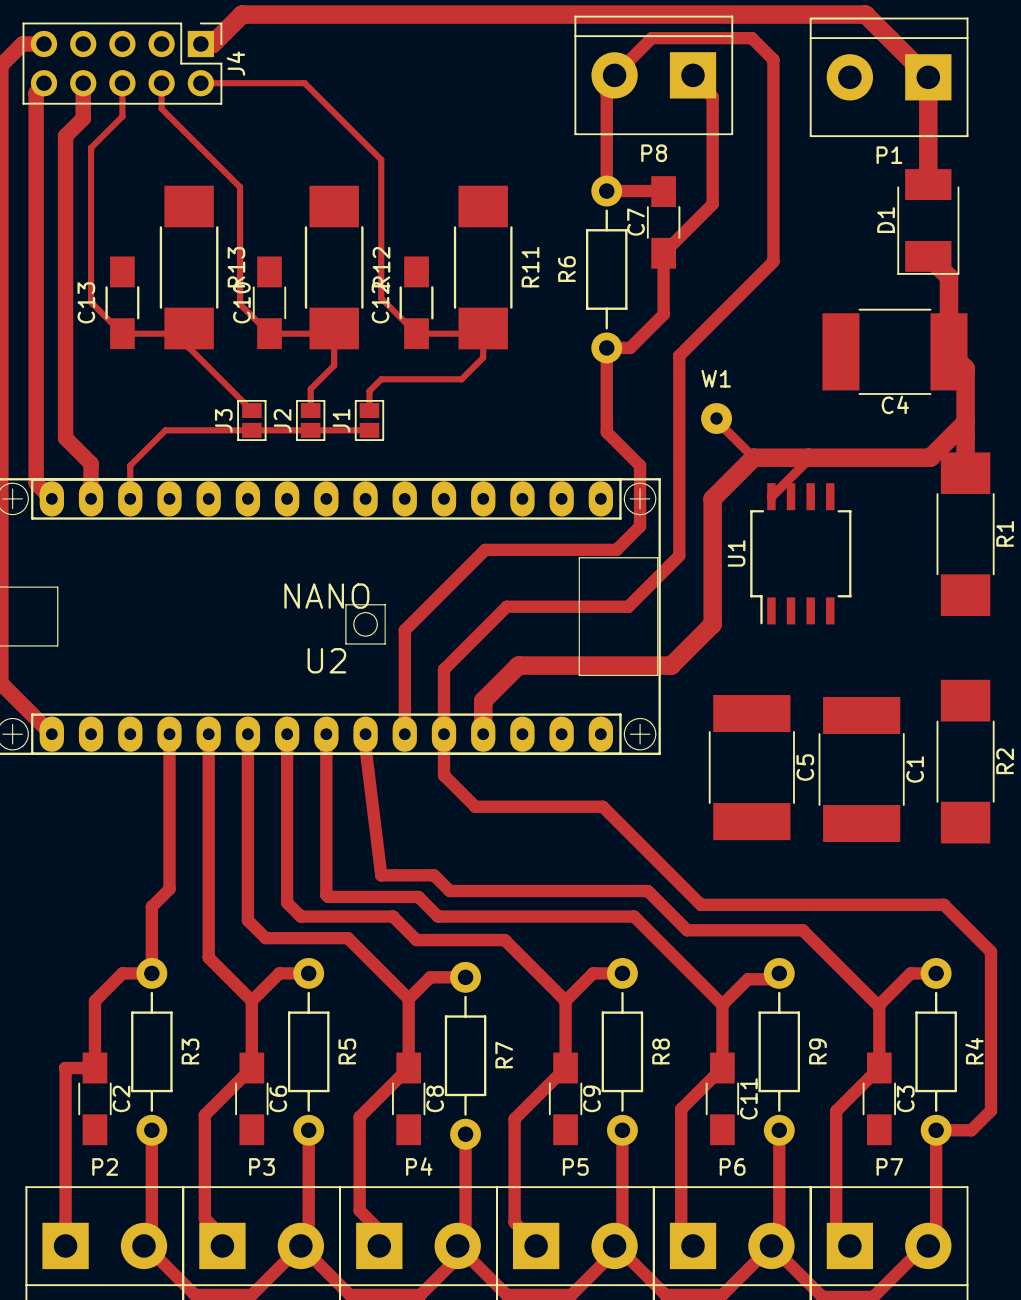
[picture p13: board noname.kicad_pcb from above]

Board: 2 copper layers, 41 parts (0 on the bottom side), 19 nets.

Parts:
C1, C4, C5: 10uF; C_2220_HandSoldering
C2, C3, C6, C7, C8, C9, C10, C11, C12, C13: 100nF; C_1206_HandSoldering
D1: schottky; D_2114
J1, J2, J3: GS2
J4: Conn_02x05_Odd_Even; Pin_Header_Straight_2x05_Pitch2.54mm
P1: V_IN; TerminalBlock_bornier-2_P5.08mm
P2: PINZA_1; TerminalBlock_bornier-2_P5.08mm
P3: PINZA_2; TerminalBlock_bornier-2_P5.08mm
P4: PINZA_3; TerminalBlock_bornier-2_P5.08mm
P5: PINZA_4; TerminalBlock_bornier-2_P5.08mm
P6: PINZA_5; TerminalBlock_bornier-2_P5.08mm
P7: PINZA_6; TerminalBlock_bornier-2_P5.08mm
P8: PINZA_7; TerminalBlock_bornier-2_P5.08mm
R1, R2, R11, R12, R13: 4K7; R_2512_HandSoldering
R3, R4, R5, R6, R7, R8, R9: 10k; Resistor_Horizontal_RM10mm
U1: LM358; SO-8_5.3x6.2mm_Pitch1.27mm
U2: NANO; arduino_nano
W1: +5V; SolderWirePad_single_0-8mmDrill

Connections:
/esp_d0: C13.1, J3.2, J4.6, R13.2
/esp_d1: C10.1, J2.2, J4.4, R12.2
/esp_d2: C12.1, J1.2, J4.2, R11.2
/intensidad_1: C2.1, P2.1, R3.1, U2.19
/intensidad_2: C6.1, P3.1, R5.1, U2.20
/intensidad_3: C8.1, P4.1, R7.1, U2.21
/intensidad_4: C9.1, P5.1, R8.1, U2.22
/intensidad_5: C11.1, P6.1, R9.1, U2.23
/intensidad_6: C3.1, P7.1, R4.1, U2.24
/intensidad_7: C7.1, P8.1, R6.1, U2.25
/miso: J4.10, U2.15
/mosi: J4.8, U2.14
/sck: J4.9, U2.16
/ss: J1.1, J2.1, J3.1, U2.13
/v_referencia: C2.2, C3.2, C5.1, C6.2, C7.2, C8.2, C9.2, C11.2, P2.2, P3.2, P4.2, P5.2, P6.2, P7.2, P8.2, R3.2, R4.2, R5.2, R6.2, R7.2, R8.2, R9.2, U1.1, U1.2, U2.26
/vcc_5v: D1.2, J4.1, P1.1
GND: C1.2, C4.2, C5.2, C10.2, C12.2, C13.2, J4.7, P1.2, R2.2, U1.4, U2.29
unnamed: C1.1, R1.2, R2.1, U1.3
VCC: C4.1, D1.1, R1.1, R11.1, R12.1, R13.1, U1.8, U2.27, W1.1

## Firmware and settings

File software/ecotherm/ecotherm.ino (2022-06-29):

/*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
You should have received a copy of the GNU General Public License
along with this program. If not, see <http://www.gnu.org/licenses/>. 
*/


/*


Medida continua
===============
Medida contiuna de:   0: Pulsos, 
                      1: Valores Analógicos 
                      2: Temperaturas
                        
* Cada ciclo se hace solo una tarea
* El obhetivo es habilitar las interrupciones a los 10 ms

Al final del ciclo (60.000 ms)
==============================
* Imprimir valores de  0: Pulsos, 
                       1: Valores Analógicos 
                       2: Temperaturas
                        
* Reiniciar registros: 1: Valores Analógicos
    (numero samples)   2: Temperaturas
              

Pulsos
=======
Contados mediante interrupciones PCINT
Cada interrupción inhabilita otras para evitar rebotes
La inhabilitacion es durante 10ms 
Los 10 ms se comprueban cada ciclo
A estos ms hay que sumar el tiempo de las tareas activas
la mas larga es la lectura de temperatura: 14ms

Valores Analógicos
==================
Se suman todos los valores durante el ciclo
El resultado es la media

Media de Temperatura
====================
La medida de temperatura se hace con sensores ds18b20
* La conversion lleva casi 1 segundo.
* Se realiza una conversion antes de cada pregunta: Case 0
* La temporizacion de la conversión se hace mediante registro de tiempo: case 1
* Mientras la conversion otras tareas son ejecutadas
* El tiempo de comunicación de la temperatura es de 14ms: case 2
* Transmitir las temperaturas es otra tarea: case 3

*/
#define DEBUG 0

#define BPS 115200

#define TX_PERIOD 59000

#include "contador_pcint.h"

#include "medida_18b20.h"

#include "medida_analogica.h"

uint32_t t_last_tx;


void setup() {

  Serial.begin(BPS);
  if(DEBUG)Serial.println(F("Measurement start "));
  if(DEBUG)Serial.println(F("temperature, flow rate and analog values "));

  //analogReference(INTERNAL);

  temperatureSensorsBegin();

  pcintCounterSetup();

  t_last_tx= millis();

  delay(100);
}

void loop() {

  CounterStep.doStep();
  TemperatureStep.doStep();
  AnalogicStep.doStep();  

  uint32_t current_time= millis();

  if (current_time < t_last_tx) t_last_tx = current_time;
  if ((current_time - t_last_tx) > TX_PERIOD){
    
    if(DEBUG)Serial.print(F("****** TX- sgs: "));
    if(DEBUG)Serial.println(millis() / 1000);
    
    t_last_tx = current_time;

    AnalogicStep.next_task=1;    //Transmit the values of the parameters 
    CounterStep.nextTask=1;      //Transmit the values of the parameters 
    TemperatureStep.nextTask=3;  //Transmit the values of the parameters 
  }
}

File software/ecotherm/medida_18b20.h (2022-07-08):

/*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
You should have received a copy of the GNU General Public License
along with this program. If not, see <http://www.gnu.org/licenses/>. 
*/

#ifndef medida_18b20_h
#define medida_18b20_h

// *******************************************************
// ***** CONFIGURATION OF BUSES FORMED BY 18B20    *******
// *******************************************************

//pins assigned to buses 
#define BUSES 12,11,10

// *******************************************************

#include <OneWire.h>
#include <DallasTemperature.h>

OneWire ds18x20[] = { BUSES };
const int oneWireCount = sizeof(ds18x20)/sizeof(OneWire);

DallasTemperature busM[oneWireCount];

//Number of sensors detected on each bus 
uint8_t sensorsNumM[oneWireCount]={};
// Address of each detected sensor 
// maximum of 6 sensors on each bus, adress matrix
uint8_t addressM[oneWireCount][6][8]={};

// sum of the temperature values sampled
int32_t tempValueM[oneWireCount][6];
uint16_t tempSamplesM[oneWireCount][6];

uint8_t busR = 0; // bus Routine
uint8_t devR = 0; // device Routine


/*****  Functions */

void temperatureSensorsBegin();
void getAdresses();
void doConversion();
void buildTemperatureMessage();
String printAddress(DeviceAddress deviceAddressPa);
String printShortA(DeviceAddress deviceAddressPa);
void copyDevice(DeviceAddress, uint8_t *);
void resetTemperatures();


void temperatureSensorsBegin() {

  for (int i = 0; i < oneWireCount; i++) {;
    busM[i].setOneWire(&ds18x20[i]);
    busM[i].begin();
  }

  getAdresses();
  doConversion();
  busR = 0; devR = 0;
  delay(100);
  
}

void getAdresses() {
  DeviceAddress tempDeviceAddress;
  for (uint8_t b = 0; b < oneWireCount; b++){

    sensorsNumM[b] = busM[b].getDeviceCount();
    if(DEBUG){Serial.print(F("number Of Devices: "));}
    if(DEBUG){Serial.println(sensorsNumM[b]);}

    for(int i=0;i<sensorsNumM[b]; i++){
      busM[b].getAddress(tempDeviceAddress, i); 
      if(DEBUG){Serial.print(F("tempDeviceAddress: "));}
      if(DEBUG){Serial.println(printAddress(tempDeviceAddress));}
      
      copyDevice(tempDeviceAddress, addressM[b][i]);
      if(DEBUG){Serial.print(F("addressM[b][i]: "));}
      if(DEBUG){Serial.println(printAddress(addressM[b][i]));}
    }
  }
}


void doConversion() {
  for (uint8_t b = 0; b < oneWireCount; b++){
    busM[b].setWaitForConversion(false);
    busM[b].requestTemperatures();
  }
}

void buildTemperatureMessage() {
  String messageToTx ="";
  
  for(int i=0;i<sensorsNumM[busR]; i++){
    if (DEBUG) {Serial.print(F("tempValueM[busR][i]: ")); Serial.println(tempValueM[busR][i]);}
    if (DEBUG) {Serial.print(F("tempSamplesM[busR][i]: ")); Serial.println(tempSamplesM[busR][i]);}
    
 
    float tempC = busM[busR].rawToCelsius(tempValueM[busR][i]/tempSamplesM[busR][i]);
    
    messageToTx += printShortA(addressM[busR][i]);
    messageToTx += ":";
    messageToTx += String(tempC,1);
    if (i != (sensorsNumM[busR] -1)) {messageToTx +=",";} 
       
  }
  if (DEBUG) Serial.println(F("messageToTx: "));
  if(messageToTx != "")Serial.println(messageToTx);
}


String printAddress(DeviceAddress deviceAddressPa){
  String string_temp_r="";
  for (uint8_t i = 0; i < 8; i++){
    if (deviceAddressPa[i] < 16) string_temp_r += ("0");
    uint8_t temp= (deviceAddressPa[i]);
    String stringTemp =  String(temp, HEX);
    string_temp_r = string_temp_r +stringTemp;
  }
  return string_temp_r;
}

String printShortA(DeviceAddress deviceAddressPa){
  String stringShort="";
  for (uint8_t i = 1; i < 3; i++){
    if (deviceAddressPa[i] < 16) stringShort += ("0");
    uint8_t temp= deviceAddressPa[i];
    stringShort += String(temp, HEX);
  }
  return stringShort;
}

void copyDevice(DeviceAddress deviceAddressOr, uint8_t * deviceAddressDest){
  unsigned char arrayIndex = 0 ;
  while(arrayIndex < 8) {
    deviceAddressDest[arrayIndex] = deviceAddressOr[arrayIndex] ;
    arrayIndex++ ;
  }
}


/*
 * 
Media de Temperatura
====================
La medida de temperatura se hace con sensores ds18b20
* La conversion lleva casi 1 segundo.
* Se realiza una conversion antes de cada pregunta: Case 0
* La temporizacion de la conversión se hace mediante registro de tiempo: case 1
* Mientras la conversion otras tareas son ejecutadas
* El tiempo de comunicación de la temperatura es de 14ms: case 2
* Transmitir las temperaturas es otra tarea: case 3

*/

/******* contador step *****************/
// => comprobar que la variable estática funciona bien

struct temperatureStep{
  uint8_t  nextTask;
  uint32_t time_output;
  
  void doStep(){
    switch (nextTask) {
      case 0:
        doConversion();
        busR =0; devR=0;
        time_output= millis()+1000;
        nextTask =1;
        break;
        
      case 1:
        if(millis()>time_output) nextTask = 2;
        else nextTask =1;
        break;
        
      case 2:
        if(busR < oneWireCount){
          if(devR < sensorsNumM[busR]){
            int16_t temp = busM[busR].getTemp(addressM[busR][devR]);
            tempValueM[busR][devR] += temp;
            tempSamplesM[busR][devR]++;
            devR++;  
            if (DEBUG) Serial.println(temp);
          }
          else {busR++; devR=0;} 
        }
        else{ nextTask = 0;}
        break;

      case 3:
        busR=0; devR=0;
        nextTask=4;
        break;
                
      case 4:
        if(busR < oneWireCount){
          buildTemperatureMessage();
          busR++;
          nextTask=4;
        }
        else{resetTemperatures();nextTask=0;}
        break;
        
      default:
        // statements
        break;
    } // switch
  }// doStep
};// struct

temperatureStep TemperatureStep = {0,millis()};

void resetTemperatures(){
  for (uint8_t b = 0; b < oneWireCount; b++){
    for(int i=0;i<sensorsNumM[b]; i++){
      tempValueM[b][i] = 0;
      tempSamplesM[b][i] = 0;
      if(DEBUG){Serial.print(F("tempValueM, tempSamplesM =0 "));Serial.println(printAddress(addressM[b][i]));}
    }
  }
}

/********FIN contador step *************/

#endif

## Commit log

2021-05-23 first operative version
    [ecoBeat_3-B.CrtYd.gbr, ecoBeat_3-B.Cu.gbr, ecoBeat_3-B.Fab.gbr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]
2021-07-08 bug variable de tx rebasda
    [contador_pcint.h, ecotherm.ino, medida_analogica.h]
2021-09-12 iot-esp hw v3: side ventilation
    [ecoBeat_3-2020-12-05-08-43-21.sch, ecoBeat_3-2020-12-07-13-52-16.sch, ecoBeat_3.kicad_pcb]
2021-10-12 raspberry compatible connector
    [wat.kicad_pcb]
2021-10-24 images to the readme
    [ecoBeat_3.sch, wat.sch]
2022-06-29 numero de samples aumentado
2022-07-08 bug:temperaturas incorrectas por debajo de 0 grados
    [medida_18b20.h]

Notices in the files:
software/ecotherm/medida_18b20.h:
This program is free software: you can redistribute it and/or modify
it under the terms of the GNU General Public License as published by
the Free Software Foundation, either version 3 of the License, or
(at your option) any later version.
